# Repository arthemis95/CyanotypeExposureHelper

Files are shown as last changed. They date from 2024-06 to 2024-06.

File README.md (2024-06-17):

# CyanotypeExposureHelper

This is a tiny, shitty project helping me to properly expose Cyanotypes. The more sensible thing would be to just get a bunch of UV LEDs, and build an exposure "chamber". But that is too sensible for me. Instead I use the sun.

However the sun comes with certain issues. Like not having a constant output, because of time of day, season, or cloud coverage. I've had decent luck adjusting my exposure time by running tests on a bright sunny day with an UV Index of 8, writing down the required exposure, and multiply my exposure time by four on days with an UV Index of 2. Which makes sense, as the UV Index scale actually is linear, and correlates with the absolute amount of power in the UV. 

If it isn't clear yet, this relies on a (somewhat) cheap UV sensor that are designed to linearly correlate their output to the current UV Index. So the goal is to integrate (add) the current UV Index over time (every half second or so), until a certain cumulative exposure is reached, to then loudly beep at you.

For this I am coining the unit "UV Index Seconds" \[UVs\], and I'm pulling the (adjustable) target value of 1100 UVs out of my arse. (Some quick and dirty tests on a sunny day have lead me to believe this might be the correct ballpark. However it still is to be seen if this holds true for cloudy days. Maybe you are fancy and put a some protective transparent element over the sensor, the error should just be a linear offset.)

## Required Hardware

 - Any old (or new) Arduino, I used an Arduino Nano clone I had laying around. 
 - [A UV Sensor, I used this specific one](https://paradisetronic.com/products/uv-lichtsensor-guva-s12sd-analogem-ausgang-3-5v-240-370nm)
 - A display, I used an GME12864-11
 - Three buttons
 - A beeper (you can skip that, if you don't mind forgetting about your cyanotypes and coming back to completely fried ones)
 - Any supporting hardware you wish (I used a cheap battery, charger, and boost converter, to be guaranteed 5V)

## Usage

Figure out how to assemble this mess of wires and buttons into a coherent form (I graciously provided an enclosure you can 3D print). If I feel like it, I might even make a wiring diagram. But I'm sure you can figure it out! The one thing that isn't quite obvious is how to wire up the display, so here you go.

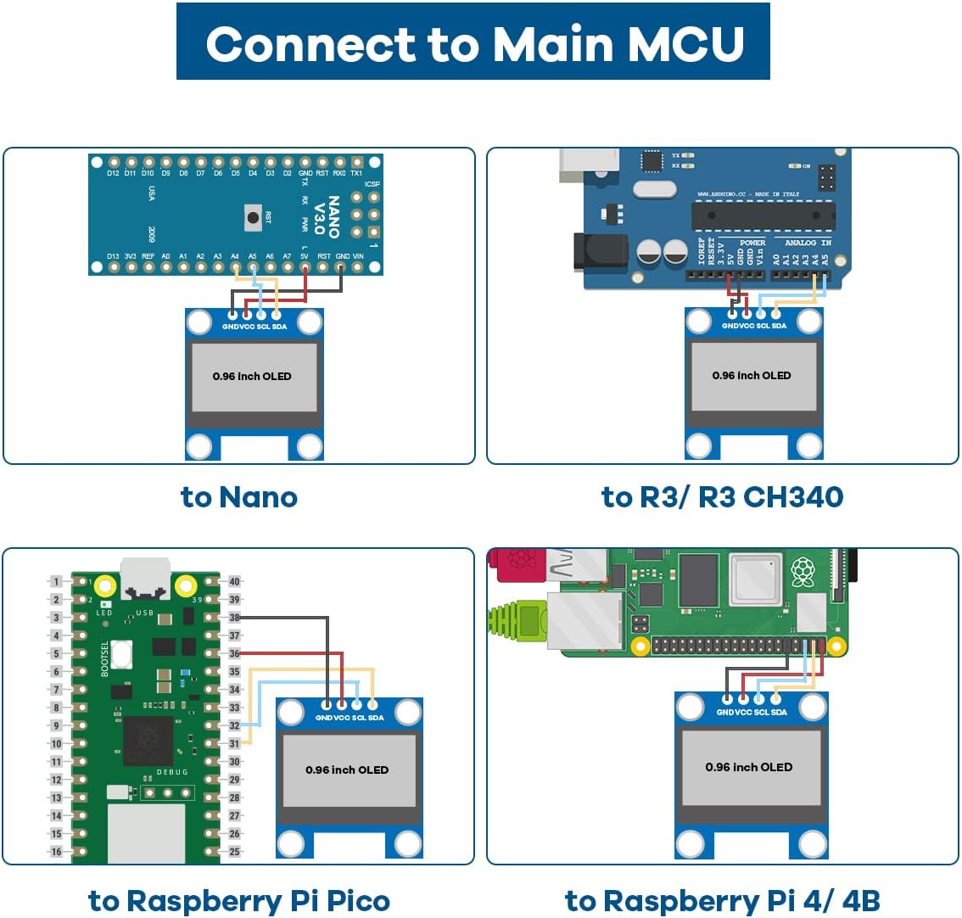
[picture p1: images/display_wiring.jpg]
Wiring diagram stolen from the Amazon listing


## FAQ
Q: Does it actually work?
A: Kinda? I've done some preliminary testing, and it seems promising.

Q: Isn't this vulnerable to the angle the light hits the sensor?
A: Yes, keep that in mind, maybe put a tiny lense on it to improve the detection angle.

Q: Why are you doing this instead of building an exposure chamber?
A: That sounds boring.

Q: This documentation sucks, your code sucks and you should do something else with your time.
A: That's not a question.

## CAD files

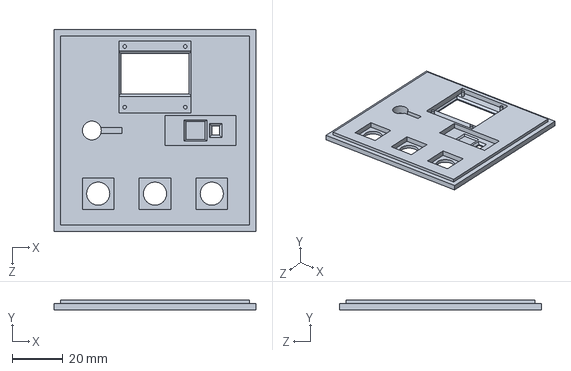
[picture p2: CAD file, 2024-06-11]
Models/Top.SLDPRT
80.0 x 4.00 x 80.0 mm

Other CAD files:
Models/Top.STL

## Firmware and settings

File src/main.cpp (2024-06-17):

#include <Arduino.h>
#include <Adafruit_SSD1306.h>
#include <Adafruit_GFX.h>
#include <Wire.h>

#define OLED_WIDTH 128
#define OLED_HEIGHT 64

#define OLED_ADDR   0x3C

#define INIT 0
#define EXPOSING 1
#define EXPOSED 2

#define UP 9
#define ENTER 8
#define DOWN 7

#define UV A7
#define VOLTAGE A1
#define BEEPER 11

int estimate_soc();
float get_UV_index();

Adafruit_SSD1306 display(OLED_WIDTH, OLED_HEIGHT);

float UV_index, target_exposure, current_exposure;
int state = 0;
int cancel, up_held, down_held, blk, SoC;

void setup() {

  display.begin(SSD1306_SWITCHCAPVCC, OLED_ADDR);
  display.clearDisplay();
  display.setTextSize(2);
  display.setTextColor(WHITE);
  display.setCursor(0, 0);
  display.println("Welcome");
  display.setTextSize(1);
  display.setTextColor(WHITE);
  display.setCursor(0, 17);
  display.println("This is");
  display.println("the Cyanotype");
  display.println("Exposure Helper");
  display.display();
  delay(2500);

  // Default target exposure
  target_exposure = 1100;


  // put your setup code here, to run once:
  pinMode(UV, INPUT_PULLUP);
  pinMode(VOLTAGE, INPUT_PULLUP);
  pinMode(BEEPER, OUTPUT);
  pinMode(UP, INPUT_PULLUP);
  pinMode(DOWN, INPUT_PULLUP);
  pinMode(ENTER, INPUT_PULLUP);

  // Make sure you are using 5V as reference voltage
  analogReference(EXTERNAL);


}
void loop() {

  // Static display
  display.clearDisplay();
  display.setTextSize(2);
  display.setTextColor(WHITE);
  display.setCursor(0, 0);
  display.println("CEH");
  UV_index = get_UV_index();
  switch (state)
  {
  // Pre Exposure Setup
  case INIT:
    // Handling Inputs

    // Increasing exposure
    if(!digitalRead(UP))
    {
      // Checking for long press
      up_held++;
      target_exposure += constrain(up_held > 10 ? 50 : 5, 0, INTMAX_MAX);
      delay(100);
    }
    else
    {
      up_held = 0;
    }

    // Decreasing exposure
    if(!digitalRead(DOWN))
    {
      // Checking for long press
      down_held++;
      target_exposure -= constrain(down_held > 10 ? 50 : 5, 0, INTMAX_MAX);
      delay(100);
    }
    else
    {
      down_held = 0;
    }

    // Starting Exposure
    if(!digitalRead(ENTER) && cancel >= 0)
    {
      current_exposure = 0;
      cancel = 0;
      state = EXPOSING;
      delay(100);
    }
    if(digitalRead(ENTER))
    {
      cancel = 0;
    }

    //Setting up Display
    display.setTextSize(1);
    display.setTextColor(WHITE);
    display.setCursor(0, 17);
    display.setTextSize(1);
    display.setTextColor(WHITE);
    display.setCursor(0, 17);
    
    display.print("UV Index: ");
    display.println(UV_index > 1. ? UV_index - 1 : 0);
    display.println("Target Exp: ");
    display.print(target_exposure);
    display.println(" [UVs]");
    break;

  // Exposing the Cyanotype
  case EXPOSING:

    current_exposure += UV_index / 2.;

    // Setting up Display
    display.println("!EXPOSING!");

    display.setTextSize(1);
    display.setTextColor(WHITE);
    display.setCursor(0, 34);

    display.print("UV Index: ");
    display.println(UV_index > 1. ? UV_index - 1 : 0);
    display.print("Exposed: ");
    display.print(constrain(100.0 * current_exposure / target_exposure, 0, 100));
    display.println("%");

    // Checking for cancellation
    if(!digitalRead(ENTER))
    {
      cancel++;
    }
    else
    {
      cancel = 0;
    }

    if(cancel > 6)
    {
      cancel = -1;
      state = INIT;
    }
    // Switching to next state
    if(current_exposure >= target_exposure)
    {
      blk = 0;
      state = EXPOSED;
    }
    delay(500);
    break;

  // All done! Sounding the alarm! 
  case EXPOSED:

    blk++;
    // BLINK ON!
    if(blk % 2)
    {
    // Setting up Display
    display.setCursor(0, 17);
    display.setTextSize(3);
    display.println("!DONE!");

    // Starting to beep!
    tone(BEEPER, 50);
    delay(500);
    }
    else
    //BLINK OFF
    {
    //Stopping the tone
    noTone(BEEPER);
    delay(250);
    }
    // Returning to INIT
    if(!digitalRead(ENTER))
    {
      state = INIT;
      noTone(BEEPER);
      cancel = -1;
      delay(50);
    }
    break;
  
  default:
    state = INIT;
    break;
  }
  display.setCursor(70, 55);
  display.setTextSize(1);
  display.print("Bat: ");
  display.print(estimate_soc());
  display.print("%");
  display.display();
}


int estimate_soc() {
    return constrain(map(analogRead(VOLTAGE), 613, 858, 0, 100), 0, 100);
}

float get_UV_index(){
  // I know that this does ignore the the -1 offset specified, but this sensor
  // actually reads 0V when there is no UV, so we would get a negative index
  // For display purpose I've applied the offset, but clamped clamped it to zero
  return analogRead(UV) * (50.0 / 1024.0);
}

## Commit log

2024-06-11 Added Models
    [Top.SLDPRT, Top.STL]
2024-06-11 Fixed some constraints, removed debug exposure offset
    [main.cpp]
2024-06-11 Updated gitignore to not include pwmo files
2024-06-11 Added display wiring graph
2024-06-11 ooops, actually added wiring diagram
2024-06-16 "Changed default exposure, fixed minor bugs"
    [main.cpp]
2024-06-17 "Fixed bug of beeper continuing to beep in 50% of cases. Updated default exposure target, adjusted how exposure is calculated, unified measurement. Updated ReadMe.md accordingly"
    [main.cpp]
